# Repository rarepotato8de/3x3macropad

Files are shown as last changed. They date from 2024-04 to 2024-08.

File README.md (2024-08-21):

# 3x3macropad: Affordable & Cool!

[Showcase](#showcase) | [Highlight Features](#highlights) | [How this Project started](#how-this-project-started) | [Build Guide](BUILD_GUIDE.md) | [QMK/VIAL Guide](QMK_GUIDE.md) | [Thanks to..](#credits)

----

Can be fully customized and programmed to your needs. It's running QMK or VIAL and has some super cool features!
title

## Highlights

* 6 (up to 9) Mechanical Switches
* EC11 Encoder (Knob)
* **Hotswap** Sockets
* **OLED Screen**
* RGB **Underglow**
* USB-C Connector (if you choose a USB-C ProMicro!)
* Runs with QMK (VIAL) - freely programmable
* Works with all major OSs, no driver needed

The coolest part of the macropad is the OLED Display on which you can display images, text and small animations<br/>
> [!NOTE]  
> This is an older version, where the screws are on the switch plate. It's only for showcasing the OLED animation

animation-bongocat-ezgif com-optimize

## Required parts

* 6x to 9x Hotswap Sockets
* 1x Arduino Pro Micro
* 1x Bottom plate, 1x PCB, 1x Switch plate
* 4x 10mm M2 Standoffs
* 8x ~5mm M2 Screws
* Mechanical MX Switches
* Keycaps
* optional: 6x SMD WS2812B LED's
* optional: 1x EC11 Encoder (15mm)
* optional: 1x 0.91" OLED Display

## Showcase

build_done_on
doggo

More images of slightly older versions can be found [here](MORE_IMAGES.md)!

## How this Project started

It all started in August 2021 when I had the first contact with custom mechanical keyboards which I've seen on youtube. I was immediately interested since I've been using membrane since I had a PC - never had a mechanical keyboard. So I wanted to get myself a decent mechanical keyboard: The problem was, I wasn't sure on what to get.
So I read myself deeper into this Hobby and was especially interested in creating something myself - PCB's. And I did it!
Started off with reading ai03's PCB guide which is really good and then thought about what would be affordable to make but also nice to use.

Small keyboards (macropads) came in my mind: I've seen some in the past, but they were quite expensive and just not as cool as I would like them to be.
So I wrote down what features I would like to have: OLED, small form factor, Encoder. After that, it was time to design it.

The Layout of this Macropads actually was the first thing I had in mind and it turned out way better than expected when I got my first PCB's.
Besides that, the case-less design was inspired by the custom keyboard I wanted to have at that time: Discipline65 - which I'm using now.
Not only does it look industrial and cool, but it also saves costs for a "dedicated" case.

Shortly after I build my first macropad and shared pictures of it, I noticed that there is quite a high demand for it. So I started offering them.

Now we here. 

In the past weeks I've gotten much love and appreciation from so many people who like my project. Thanks for that! 💜💜💜

**2024 Update:** After quite some time I got more into Git(Hub) and since I always loved and used open-source projects myself, I open-sourced this project!
You can now order the PCB's and all other stuff yourself. The PCB files (Gebers) can be uploaded to any PCB Manufacturer (e.g. JLCPCB) and be ordered for very cheap.

## Credits

Thanks to @mondrian for not only getting yourself 5 macropads, but also for creating the awesome pictures for the [Build Guide](BUILD_GUIDE.md)! 😎

## Questions?

Please feel free to message me

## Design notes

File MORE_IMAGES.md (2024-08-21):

> [!NOTE]  
> The newest version of the macropad that is on this GitHub has the screws in the PCB, not the top most switch plate. That means, that some of these pictures show older versions.
Feature wise: They're the same.<br/> The newest version was just optimized for cleaner looks and better mounting for hotswap (previous versions where solder)

black2
black3
pad1
pad3
pad7

### ... and more!
Those are just some examples! You can basically do whatever you want!

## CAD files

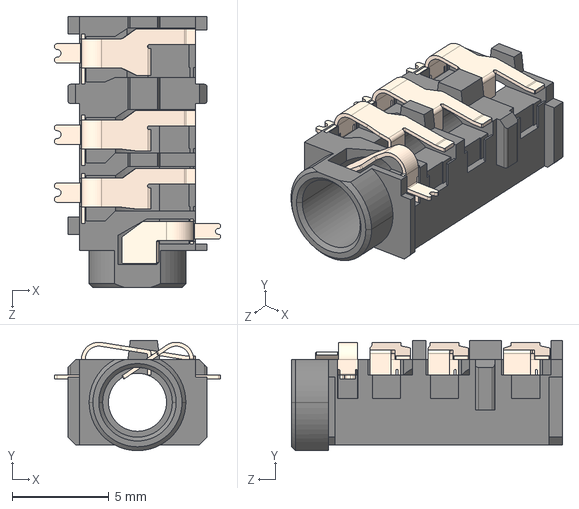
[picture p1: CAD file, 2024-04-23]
PCB-Files/PCB/Libaries/Keebio-Parts.pretty-master/3dmodels/CUI_SJ-43614-SMT-TR.step
8.60 x 5.70 x 14.0 mm

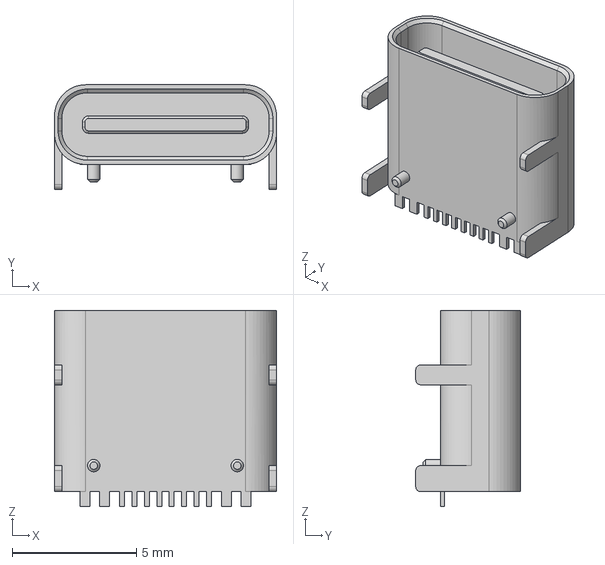
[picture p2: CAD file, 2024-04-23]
PCB-Files/PCB/Libaries/Keebio-Parts.pretty-master/3dmodels/HRO TYPE-C-31-M-12.step
8.94 x 4.21 x 7.90 mm

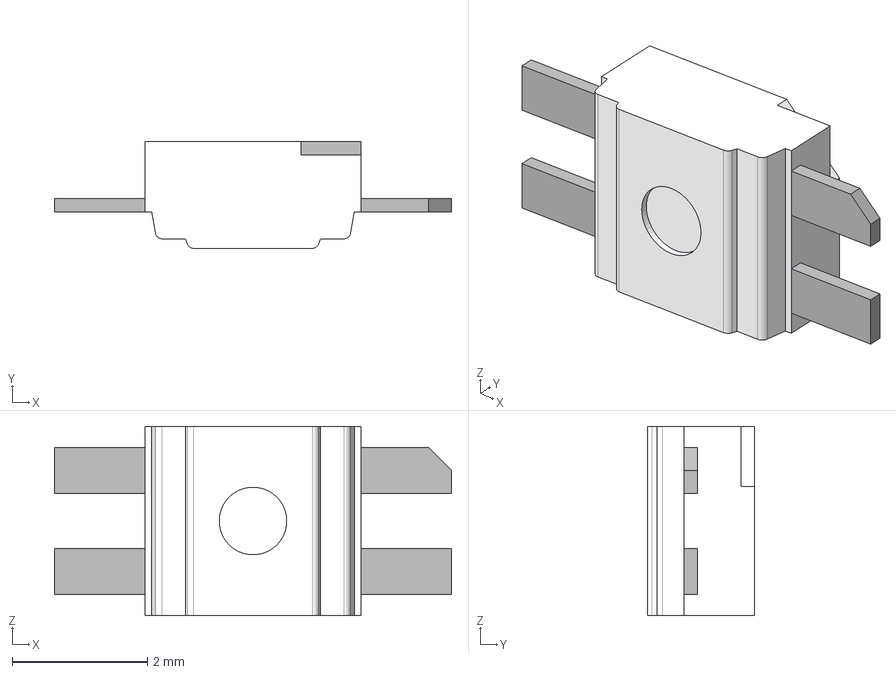
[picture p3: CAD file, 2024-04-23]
PCB-Files/PCB/Libaries/Keebio-Parts.pretty-master/3dmodels/SK6812MINI-E v1.step
5.88 x 1.58 x 2.80 mm

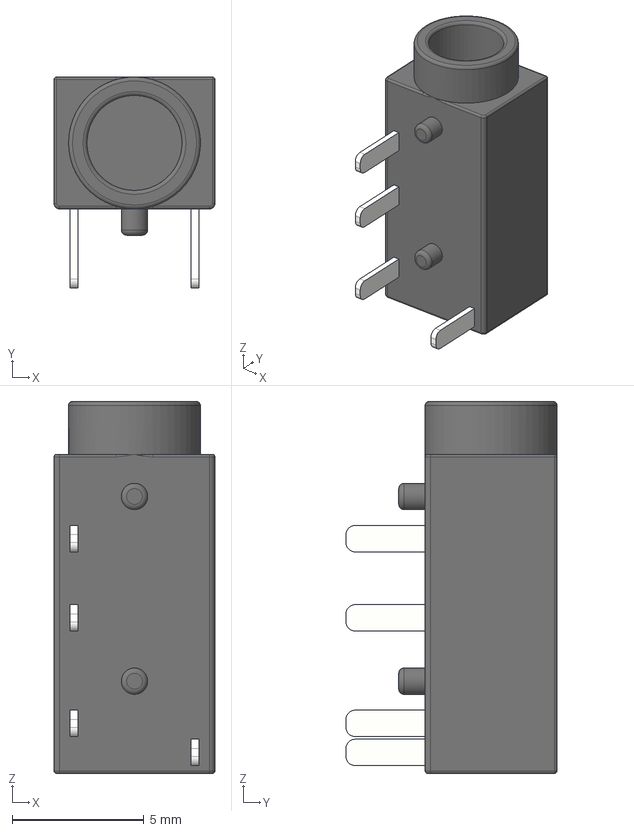
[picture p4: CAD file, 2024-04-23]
PCB-Files/PCB/Libaries/Keebio-Parts.pretty-master/3dmodels/PJ-320A.step
6.10 x 8.00 x 14.1 mm

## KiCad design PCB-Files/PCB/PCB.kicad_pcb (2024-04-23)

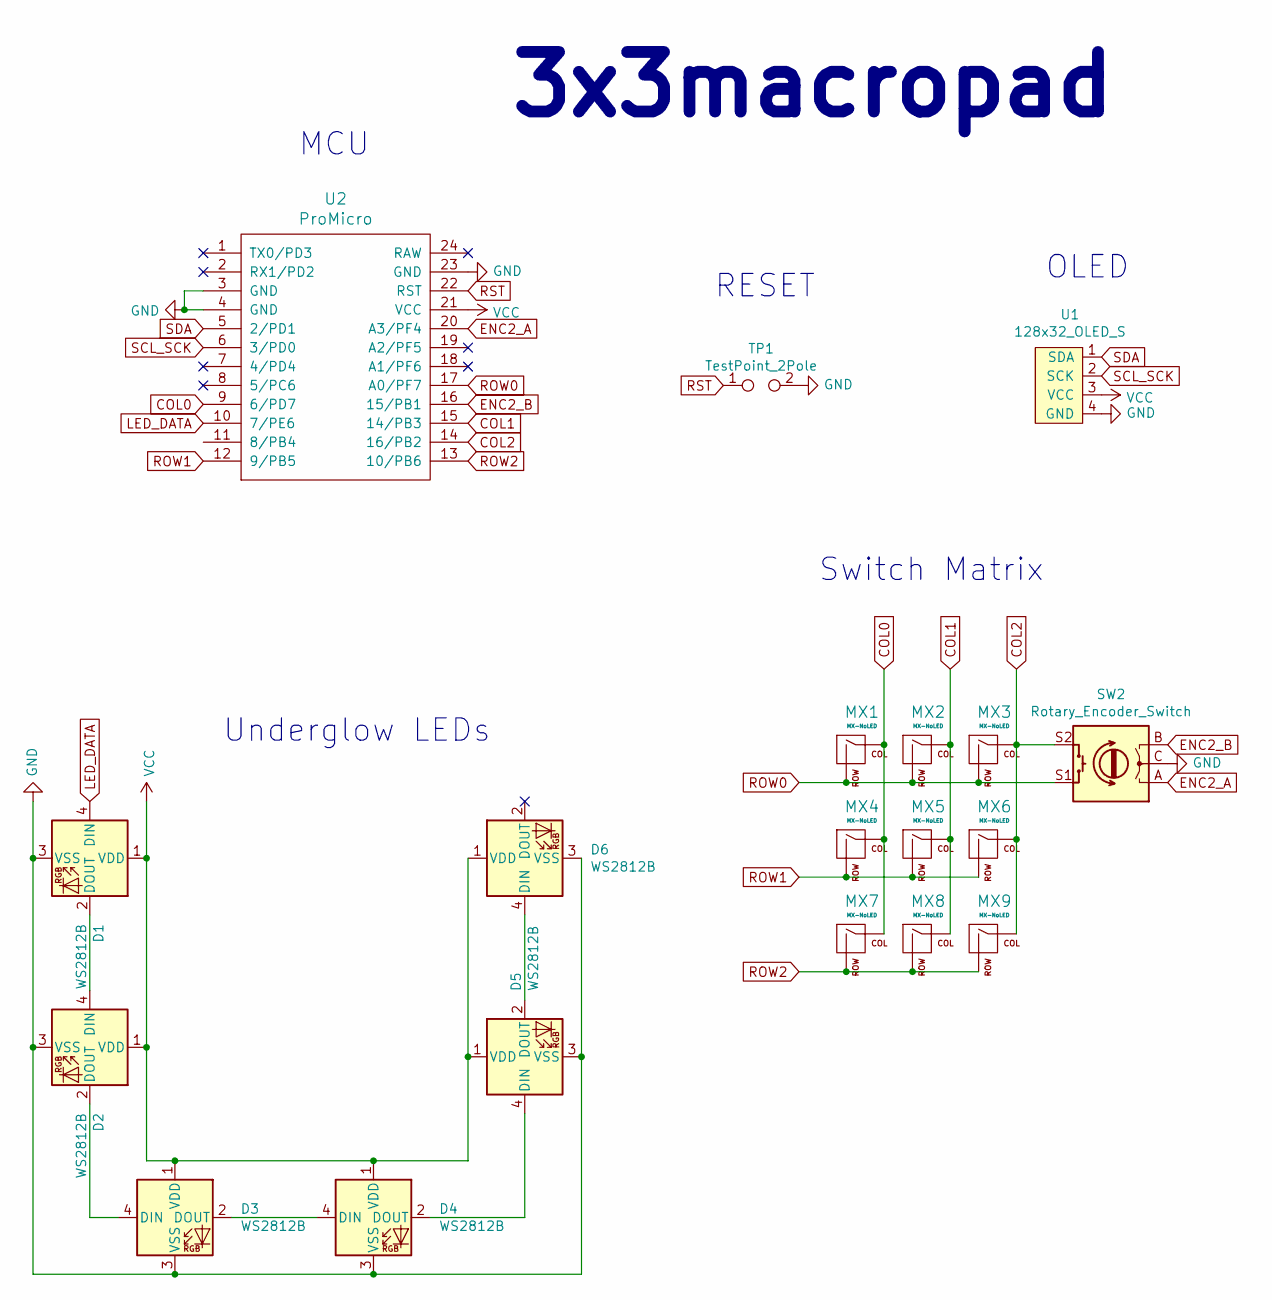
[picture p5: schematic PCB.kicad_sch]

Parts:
D1, D2, D3, D4, D5, D6: WS2812B; LED_WS2812B_PLCC4_5.0x5.0mm_P3.2mm
MX1, MX2, MX3, MX4, MX5, MX6, MX7, MX8, MX9: MX-NoLED; MXOnly-1U-Hotswap
SW2: Rotary_Encoder_Switch; RotaryEncoder_Alps_EC11E-Switch_Vertical_H20mm
TP1: TestPoint_2Pole; TestPoint_2Pads_Pitch2.54mm_Drill0.8mm
U1: 128x32_OLED_S; 128x32_OLED_F_ROTATE
U2: ProMicro; ArduinoProMicro-ZigZag

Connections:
COL0: MX1.1 (COL), MX4.1 (COL), MX7.1 (COL), U2.9 (6/PD7)
COL1: MX2.1 (COL), MX5.1 (COL), MX8.1 (COL), U2.15 (14/PB3)
COL2: MX3.1 (COL), MX6.1 (COL), MX9.1 (COL), SW2.S2, U2.14 (16/PB2)
ENC2_A: SW2.A, U2.20 (A3/PF4)
ENC2_B: SW2.B, U2.16 (15/PB1)
GND: D1.3 (VSS), D2.3 (VSS), D3.3 (VSS), D4.3 (VSS), D5.3 (VSS), D6.3 (VSS), SW2.C, TP1.2, U1.4 (GND), U2.3 (GND), U2.4 (GND), U2.23 (GND)
LED_DATA: D1.4 (DIN), U2.10 (7/PE6)
unnamed: D1.2 (DOUT), D2.4 (DIN)
unnamed: D2.2 (DOUT), D3.4 (DIN)
unnamed: D3.2 (DOUT), D4.4 (DIN)
unnamed: D4.2 (DOUT), D5.4 (DIN)
unnamed: D5.2 (DOUT), D6.4 (DIN)
ROW0: MX1.2 (ROW), MX2.2 (ROW), MX3.2 (ROW), SW2.S1, U2.17 (A0/PF7)
ROW1: MX4.2 (ROW), MX5.2 (ROW), MX6.2 (ROW), U2.12 (9/PB5)
ROW2: MX7.2 (ROW), MX8.2 (ROW), MX9.2 (ROW), U2.13 (10/PB6)
RST: TP1.1, U2.22 (RST)
SCL_SCK: U1.2 (SCK), U2.6 (3/PD0)
SDA: U1.1 (SDA), U2.5 (2/PD1)
VCC: D1.1 (VDD), D2.1 (VDD), D3.1 (VDD), D4.1 (VDD), D5.1 (VDD), D6.1 (VDD), U1.3 (VCC), U2.21 (VCC)

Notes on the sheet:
RESET
Switch Matrix
3x3macropad
Underglow LEDs
OLED
MCU

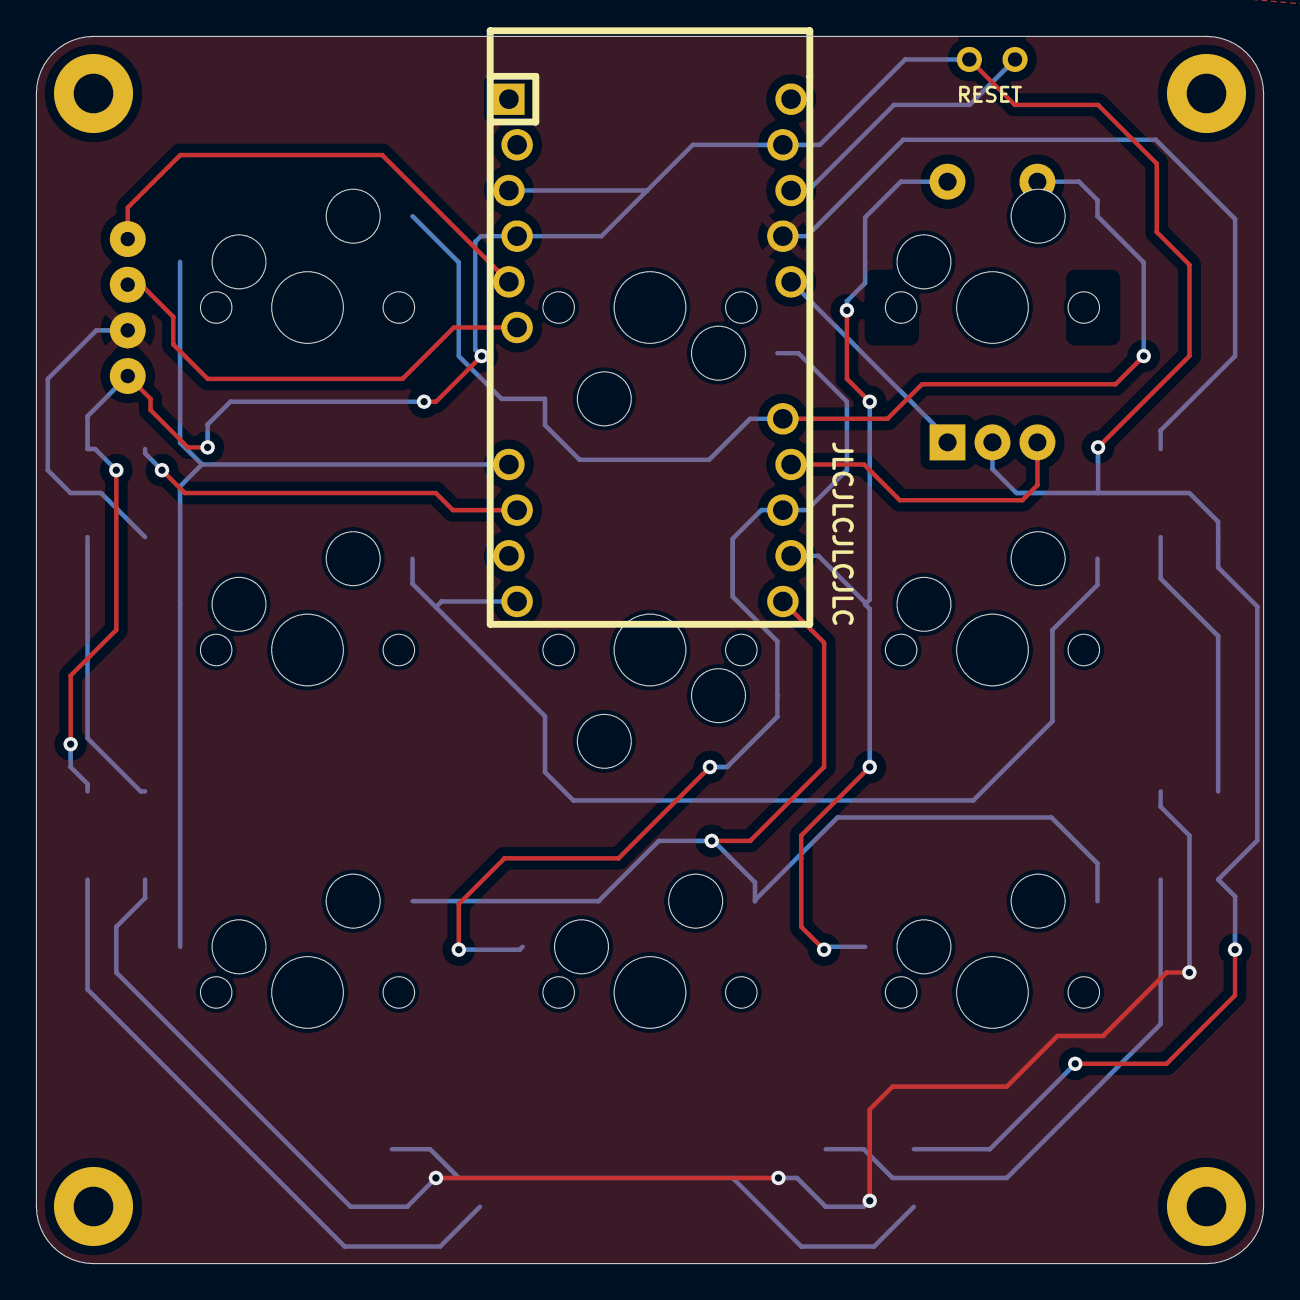
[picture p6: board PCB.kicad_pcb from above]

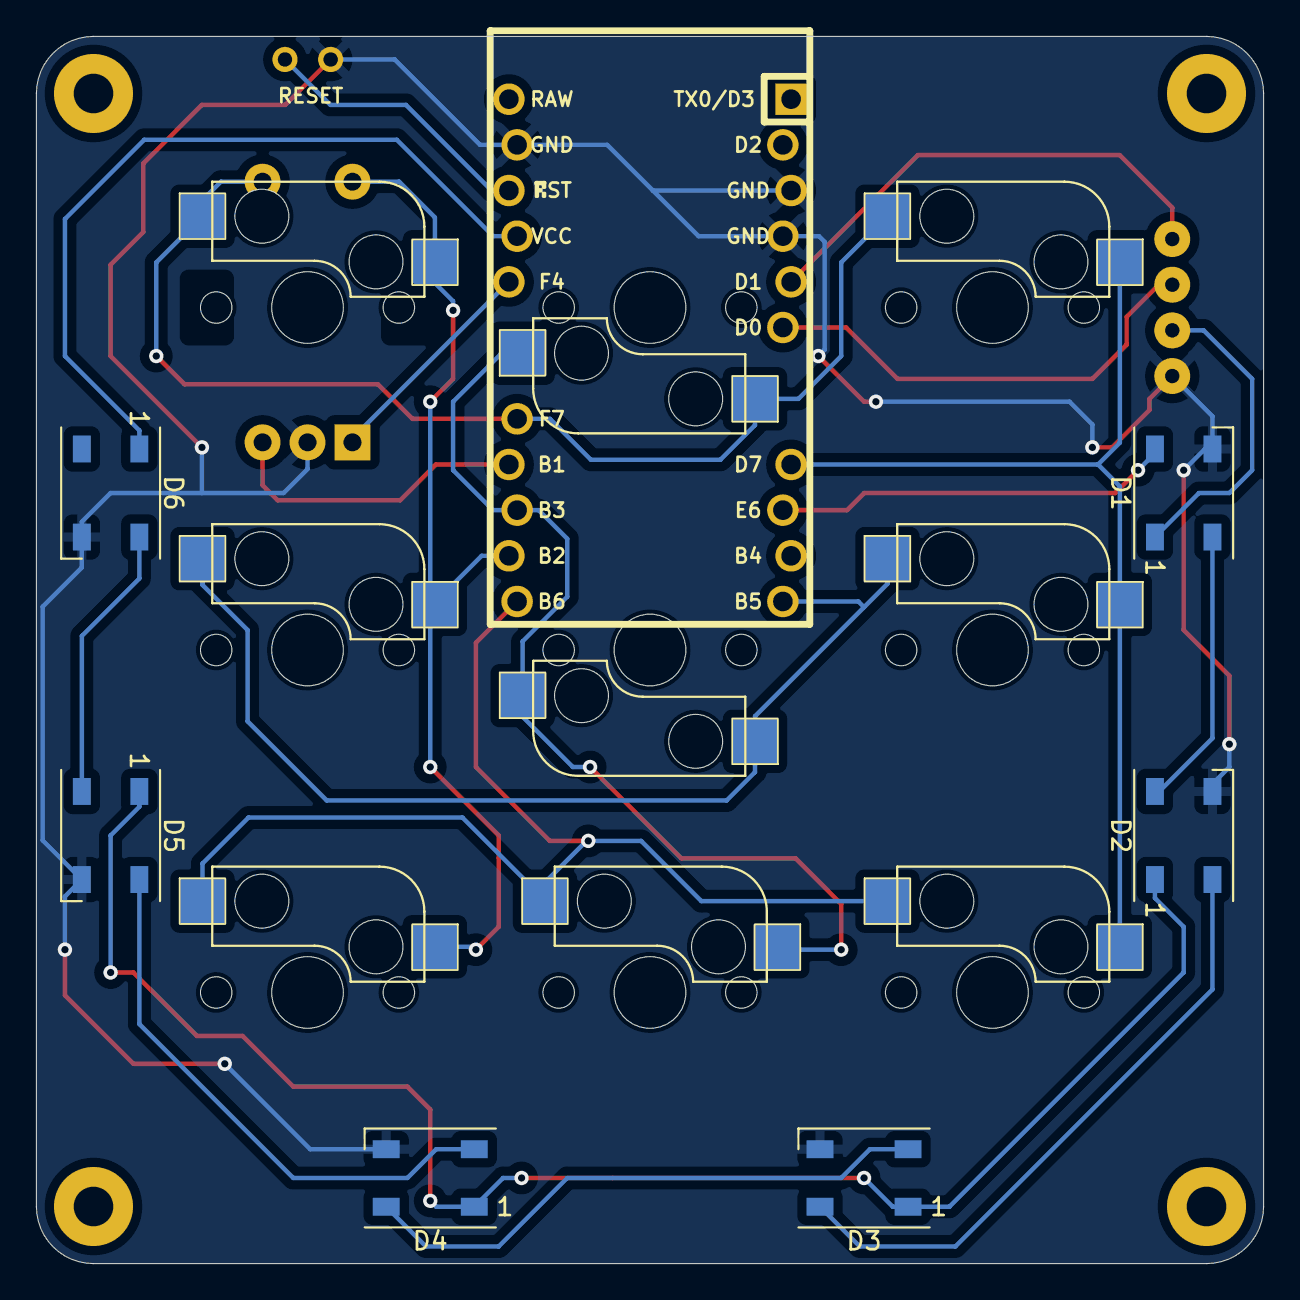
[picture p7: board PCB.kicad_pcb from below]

Board: 2 copper layers, 68.3 x 68.3 mm, 19 parts (6 on the bottom side), 19 nets.

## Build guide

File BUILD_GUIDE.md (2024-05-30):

# 3x3macropad - Build Guide

This guide provides a step-by-step explanation on how to solder/build the macropad.
Thanks to @mondrian for taking all of these pictures! He helped me so much with making this guide possible.

## Step 1: Soldering the HS Sockets and LED's
1.1 Get the PCB ready
build_empty_pcb1

1.2 Solder all of the Hotswap-Sockets you need (6 to 9, depending on your desired layout!) and optionally the LED's (The triangle/marked corner on the LED must align with the "triangle" corner on the PCB! It's diagonal from the "1" Text)
build_hs_led_2

## Step 2: Soldering the Pro Micro
2.1 Split the Header Pins like shown in the picture, since a total of 4 Pins don't have through-holes in the PCB due to the layout
build_promicro_pins_3

2.2 Insert the Header Pins like this in the PCB
build_pins_pcb

2.3 Place the Pro Micro on it (USB-Port facing towards the PCB!) and solder it's pins
build_pins_promicro

2.4 Solder all the pins on the PCB
build_pins_solder

# Step 3: Soldering the OLED and EC11 Encoder (both are optional)

3.1 Get some pliers and cut the already soldered pins as much as you can, but be careful. They still need to be soldered to the PCB!
build_cut_top_pins

3.2 Shorten these 5 Pins that are marked in the red boxes in the picture below. Otherwise they will interfere with the OLED
cut_top_pins_both_done

3.3 Get a knife or pliers and remove the black Pin Header that is on the "bottom" of the OLED Screen Pins. You can "push" them down usually.
build_remove_pin_header_oled

3.4 After that it should look like that. Then also shorten the top solder joints on the OLED, but also be careful here: Don't damage the soldered connection. 
We just want to have a little more space "above" the OLED, so the Switch Plate later fits above it.
build_shorten_oled_pins

> [!TIP]
> Before proceeding to do the next step, get yourself some tape and stick it on the bottom of the oled. It's meant to prevent possibly shorting the OLED with our PCB.

3.5 Place the OLED on the PCB like this and solder the pins from the bottom side. Make sure to hold the OLED relatively "even", so it looks good at the end
build_oled_on_pcb_flat

3.6 Now place your EC11 Encoder in the top right and solder all of it's 5 Pins: 2 at the top and 3 at the bottom
build_oled_on_pcb_flat_2

# Soldering done!

We are now done with the difficult part: The soldering. This is what it should now look from the bottom.


# Step 4: Assembling the Macropad

4.1 Screw the 4 Standoffs to the bottom plate


4.2 Place the PCB on the 4 Standoffs and screw it tight


4.2 Insert your Switches into the Plate (Note: The Switch at matrix [0, 1] and [1, 1] are north facing unlike all others!) and place it on the PCB


4.3 Put the EC11 Encoder Knob and you Keycaps on
build_done_off

# Done
Congratulations! 🎉 👏🏻 
You've build your very own 3x3macropad.
build_done_on

# Step 5: Flashing the Firmware 
5.1 The very last step to get the macropad running is flashing a firmware to the Arduino Pro Micro. for that, visit my [QMK/VIAL Guide](QMK_GUIDE.md)

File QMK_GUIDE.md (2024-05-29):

# 3x3macropad - QMK/VIAL Setup Guide

This guide provides a step-by-step explanation on how to set up QMK or VIAL, and how to modify, compile, and flash the firmware for your macropad.

## Table of Contents

1. [Preparation](#preparation)
2. [Compiling the Firmware](#compiling-the-firmware)
3. [Flashing the Firmware](#flashing-the-firmware)
4. [Resources](#resources)

## Preparation

Before you begin, make sure you have the following tools installed:
- [QMK MSYS](https://msys.qmk.fm/) - for compiling the firmware
- [QMK Toolbox](https://github.com/qmk/qmk_toolbox/releases) - for flashing the firmwre 

## Compiling the Firmware

### Step 1: Setting up QMK MSYS
1. Install [QMK MSYS](https://msys.qmk.fm/), open it up and run this in the cmd:
   ```sh
   qmk setup
  After that, keep QMK MSYS open and follow the next steps.

### Step 2: Download QMK or VIAL Firmware

1. Clone the QMK firmware repository (within QMK MSYS!):
   ```sh
   git clone https://github.com/qmk/qmk_firmware.git
   cd qmk_firmware

**OR (preffered)**

1. Clone the VIAL firmware repository (within QMK MSYS!):
   ```sh
   git clone https://github.com/vial-kb/vial-qmk.git
   cd vial-qmk

2. optional: Modify the keymap under "keyboards/rarepotato8de/3x3macropad/keymaps/..." how you like (e.g. OLED): [HERE](https://docs.splitkb.com/hc/en-us/articles/360013811280-How-do-I-convert-an-image-for-use-on-an-OLED-display) is an awesome guide on how to get pictures on your OLED!

3. Compile the Firmware with the following command:
   ```sh
   qmk compile -kb rarepotato8de/3x3macropad -km default

   or for vial:

   qmk compile -kb rarepotato8de/3x3macropad -km vial

## Flashing the Firmware

### Step 1: Installing QMK Toolbox

1. Install [QMK Toolbox](https://github.com/qmk/qmk_toolbox) and open it up (preferably as administrator)

### Step 2: Configuration/ Settings

1. Select "atmega32u4" (Chip used on the ProMicro) in the top right
2. Select the "rarepotato8de_3x3macropad_*.bin" File that you compiled on the previous step. It's located in the main/root QMK or VIAL directory, depending on what you used previously
3. Tick the "Auto-Flash" Checkbox in the top right of QMK Toolbox for ease of use. Otherwise you manually need to press the "Flash" Button after the following step.

### Step 3: Flashing

1. Short the two pins at the top right on the PCB (where the Encoder is) with tweeters, scissors or whatever you have to connect both pins together. The Pro Micro should blink and QMK Toolbox will output some text in the console. At the end it should tell you that it's done ✅ 

## Done
Success! 🎉🤩 You can now use your macropad how you want. Have fun!

### Resources

- [QMK Documentation](https://docs.qmk.fm/)
- [VIAL Documentation](https://get.vial.today/docs/)
- [Convert pictures for the OLED Screen](https://docs.splitkb.com/hc/en-us/articles/360013811280-How-do-I-convert-an-image-for-use-on-an-OLED-display)
